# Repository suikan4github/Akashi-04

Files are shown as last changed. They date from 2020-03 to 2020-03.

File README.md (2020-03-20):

# Akashi-04
Audio board for Nucleo-G431RB

## Functionality
This board is designed to provide the audio functionality for the  STM32 series MCU. 
The connectors can be directly mounted on the Nucleo 64 series board and employs I2S interface of STM32 MCU.
This board supports following Nucleo :
- STM32F446RE
- STM32G431RB

The design can be retrieved from the [github](https://github.com/suikan4github/Akashi-04) repository.

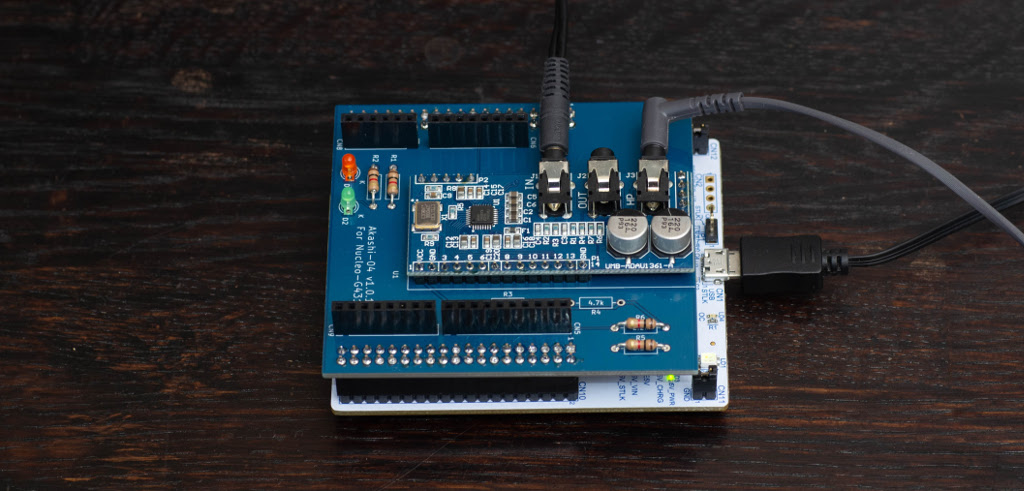
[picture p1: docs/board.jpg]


These functionalities are tested with following codec board as with I2C control line. 
- [UMB-ADAU1361A](http://dsps.shop-pro.jp/?pid=82798273)

## Development
- [KiCad 5.1](http://kicad-pcb.org/blog/2019/03/KiCad-5.1.0-Release/)
- [Nucleo G431RB](https://www.st.com/en/evaluation-tools/nucleo-g431rb.html)
- [Nucleo F446RE](https://www.st.com/en/evaluation-tools/nucleo-f446re.html)

The schematics [can be downloaded](docs/Akashi-04.pdf) as PDF format. 

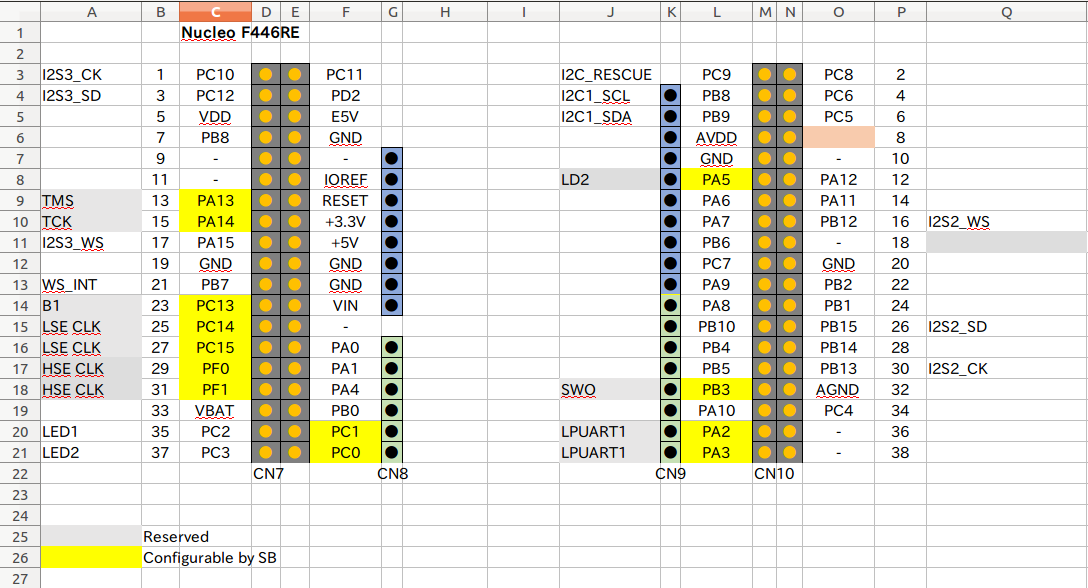
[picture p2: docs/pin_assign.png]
Pin Configurations


The configuration of special ports are :
- I2S2 : Slave TX
- I2S3 : Slave RX
- PB7 : EXTI to detect the I2S WS edge. 
- PC9 : Open Drain output. To save the struggled I2C device.

## I2C address
By default, the I2C device address are configured as ***0x38*** ( 7bit address ). 
If you want to change, you should modify the short bridge as following : 

| JP1    | JP2    | Address |
---------|--------|---------|
| Closed | Closed | 0x38    |
| Open   | Closed | 0x39    |
| Closed | Open   | 0x3A    |
| Open   | Open   | 0x3B    |

Note that R3 and R4 are needed if JP1 and JP2 are cut, respectively

## Usage
To clone this project, follow :
```
git clone repository-of-this-project
git submodule update
```

The sample programs are published as [murasaki_samples_audio](https://github.com/suikan4github/murasaki_samples_audio) repositories. 

 To use these repository, follow the sequence :
 1. Clone the murasaki_samples_audio repository
 1. Import to CubeIDE

Caution : Because of the height of the capacitor, the stacked Arduino board may contact to the capacitor. 

## License
This PCB design is released under the [Creative Commons Attribution 4.0 International license](https://creativecommons.org/licenses/by/4.0/). 
You are welcome to use this design for commercial purposes.

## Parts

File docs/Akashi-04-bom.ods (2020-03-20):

Reference | Quantity | Value | Footprint | Datasheet
CN5 | 1 | Conn_01x10 | Connector_PinHeader_2.54mm:PinHeader_1x10_P2.54mm_Vertical | Arduino Stackable
CN6 CN9 | 2 | Conn_01x08 | Connector_PinHeader_2.54mm:PinHeader_1x08_P2.54mm_Vertical | Arduino Stackable
CN8 | 1 | Conn_01x06 | Connector_PinHeader_2.54mm:PinHeader_1x06_P2.54mm_Vertical | Arduino Stackable
CN7 CN10 | 2 | Conn_02x19 | Connector_PinSocket_2.54mm:PinSocket_2x19_P2.54mm_Vertical | PPPC192LFBN-RC
D1 D2 | 2 | LED | LED_THT:LED_D3.0mm_Clear | ~
R1 R2 | 2 | 1k | Resistor_THT:R_Axial_DIN0207_L6.3mm_D2.5mm_P10.16mm_Horizontal | ~
R3 | 1 | 4.7k | Resistor_THT:R_Axial_DIN0207_L6.3mm_D2.5mm_P10.16mm_Horizontal | ~
R9 R5 | 2 | 2.2k | Resistor_THT:R_Axial_DIN0207_L6.3mm_D2.5mm_P10.16mm_Horizontal | ~
U1 | 1 | UMB-ADAU1361A | Codec_Modules:UMB-ADAU1361A | http://dsps.shop-pro.jp/?pid=82798273

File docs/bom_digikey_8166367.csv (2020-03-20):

メーカー品番 | 仕入先 | Digi-Key品番 | 客先参照品番（任意） | 参照名 | 梱包形態 | 部品状況 | 数量 | 単価 | 金額 | 在庫数量 | メーカー標準リードタイム | 商品概要 | RoHS ステータス | 鉛フリーステータス | REACHステータス
PPPC192LFBN-RC | Sullins Connector Solutions | S7122-ND |  | CN7,CN10 | トレイ | アクティブ | 2 | 265.00000 | ¥530 | 798 | 5 週間 | CONN HDR 38POS 0.1 GOLD PCB | ROHS3対応 | 鉛フリー | REACHの影響なし
85 | Adafruit Industries LLC | 1528-1074-ND |  | CN5,CN6,CN8,CN9 | バルク | アクティブ | 1 | 229.00000 | ¥229 | 3872 | 4 週間 | STACKING HEADER ARDUINO SHIELD | ROHS3対応 | 鉛フリー | Not Available

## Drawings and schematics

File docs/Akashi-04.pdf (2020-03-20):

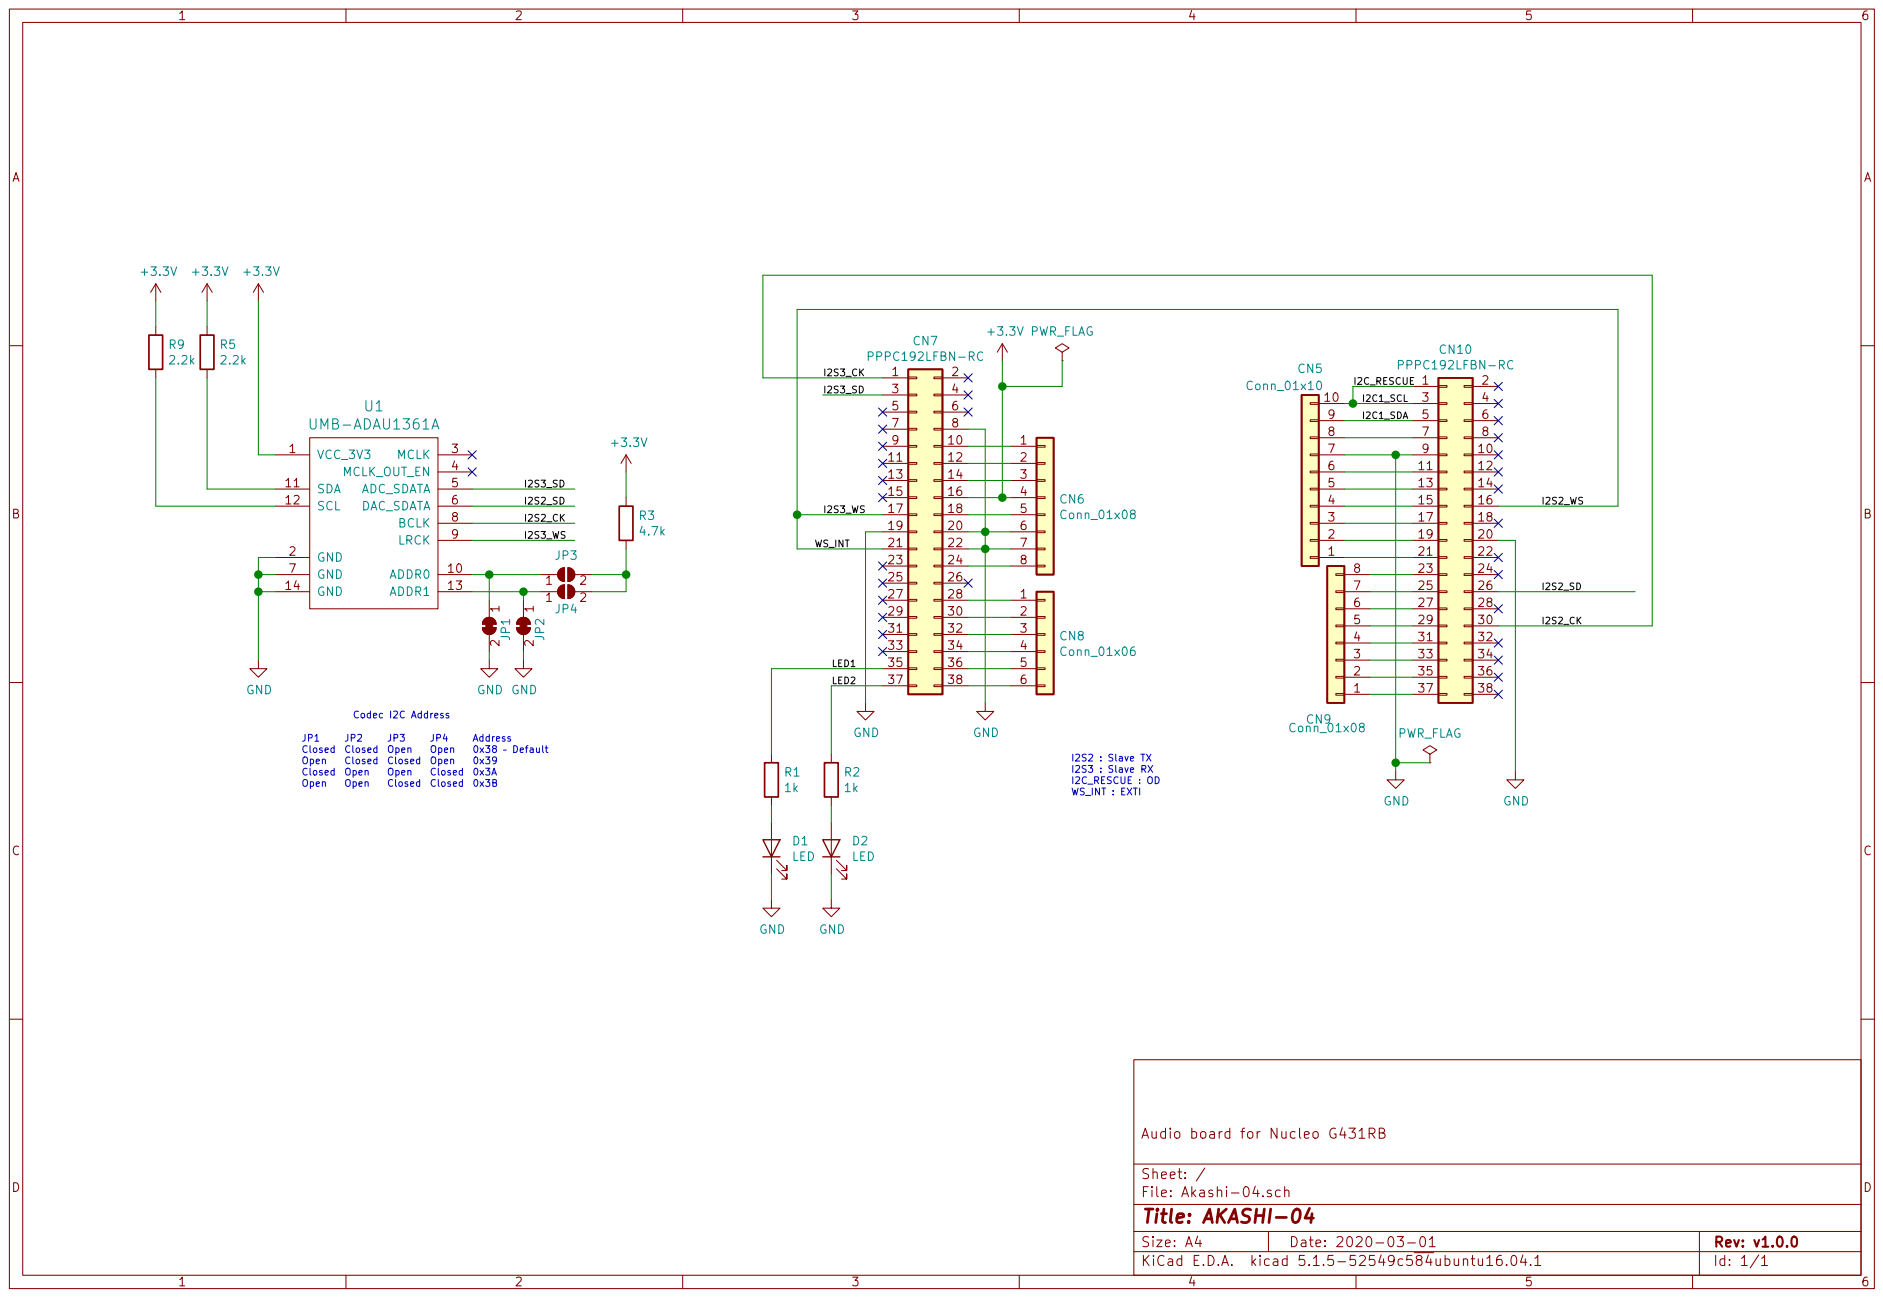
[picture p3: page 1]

19 | 20 | 6
21 | 22 | 7

8 CN9 Conn_01x08 5 | 29

LED2 | 37 | 38

JP1 Closed Open Closed Open

JP2 Closed Closed Open Open

JP3 Open Closed Open Closed

JP4 Open Open Closed Closed

File: Akashi-04.sch Sheet: / Audio board for Nucleo G431RB

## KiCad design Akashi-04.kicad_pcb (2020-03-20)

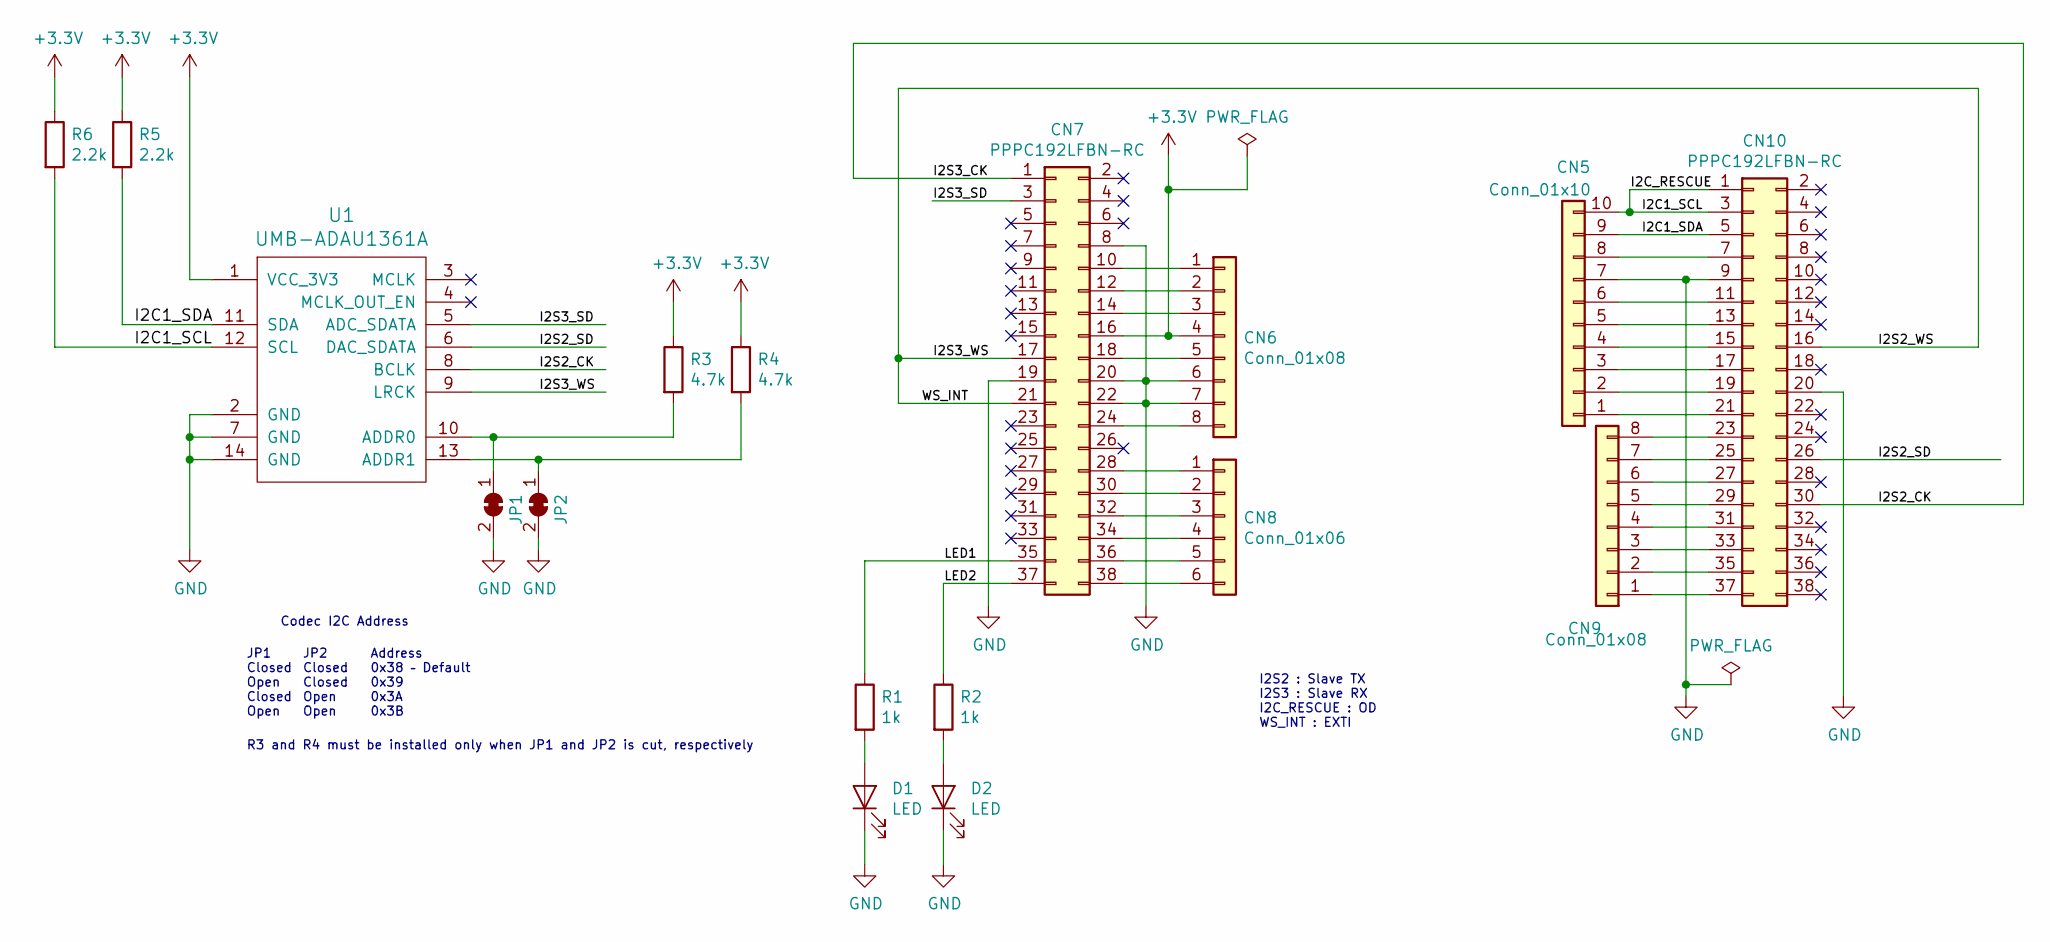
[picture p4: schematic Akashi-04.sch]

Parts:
CN5: Conn_01x10; PinHeader_1x10_P2.54mm_Vertical
CN6, CN9: Conn_01x08; PinHeader_1x08_P2.54mm_Vertical
CN7, CN10: PPPC192LFBN-RC; PinSocket_2x19_P2.54mm_Vertical
CN8: Conn_01x06; PinHeader_1x06_P2.54mm_Vertical
D1, D2: LED; LED_D3.0mm_Clear
JP1, JP2: SolderJumper_2_Bridged; SolderJumper-2_P1.3mm_Bridged_RoundedPad1.0x1.5mm
R1, R2: 1k; R_Axial_DIN0207_L6.3mm_D2.5mm_P10.16mm_Horizontal
R3, R4: 4.7k; R_Axial_DIN0207_L6.3mm_D2.5mm_P10.16mm_Horizontal
R5, R6: 2.2k; R_Axial_DIN0207_L6.3mm_D2.5mm_P10.16mm_Horizontal
U1: UMB-ADAU1361A

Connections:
+3V3: CN6.4, CN7.16, R3.1, R4.1, R5.1, R6.1, U1.1 (VCC_3V3)
/I2C1_SCL: CN5.10, CN10.1, CN10.3, R6.2, U1.12 (SCL)
/I2C1_SDA: CN5.9, CN10.5, R5.2, U1.11 (SDA)
/I2S2_CK: CN7.1, CN10.30, U1.8 (BCLK)
/I2S2_SD: CN10.26, U1.6 (DAC_SDATA)
/I2S2_WS: CN7.17, CN7.21, CN10.16, U1.9 (LRCK)
/I2S3_SD: CN7.3, U1.5 (ADC_SDATA)
/LED1: CN7.35, R1.1
/LED2: CN7.37, R2.1
GND: CN5.7, CN6.6, CN6.7, CN7.8, CN7.19, CN7.20, CN7.22, CN10.9, CN10.20, D1.1 (K), D2.1 (K), JP1.2 (B), JP2.2 (B), U1.2 (GND), U1.7 (GND), U1.14 (GND)
unnamed: CN6.1, CN7.10
unnamed: CN6.2, CN7.12
unnamed: CN6.3, CN7.14
unnamed: CN6.5, CN7.18
unnamed: CN6.8, CN7.24
unnamed: CN7.28, CN8.1
unnamed: CN7.30, CN8.2
unnamed: CN7.32, CN8.3
unnamed: CN7.34, CN8.4
unnamed: CN7.36, CN8.5
unnamed: CN7.38, CN8.6
unnamed: CN5.8, CN10.7
unnamed: CN5.6, CN10.11
unnamed: CN5.5, CN10.13
unnamed: CN5.4, CN10.15
unnamed: CN5.3, CN10.17
unnamed: CN5.2, CN10.19
unnamed: CN5.1, CN10.21
unnamed: CN9.8, CN10.23
unnamed: CN9.7, CN10.25
unnamed: CN9.6, CN10.27
unnamed: CN9.5, CN10.29
unnamed: CN9.4, CN10.31
unnamed: CN9.3, CN10.33
unnamed: CN9.2, CN10.35
unnamed: CN9.1, CN10.37
unnamed: D1.2 (A), R1.2
unnamed: D2.2 (A), R2.2
unnamed: JP1.1 (A), R3.2, U1.10 (ADDR0)
unnamed: JP2.1 (A), R4.2, U1.13 (ADDR1)

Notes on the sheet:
JP1 Closed Open Closed Open
JP2 Closed Closed Open Open
Address 0x38 – Default 0x39 0x3A 0x3B
Codec I2C Address
I2S2 : Slave TX I2S3 : Slave RX I2C_RESCUE : OD WS_INT : EXTI
R3 and R4 must be installed only when JP1 and JP2 is cut, respectively

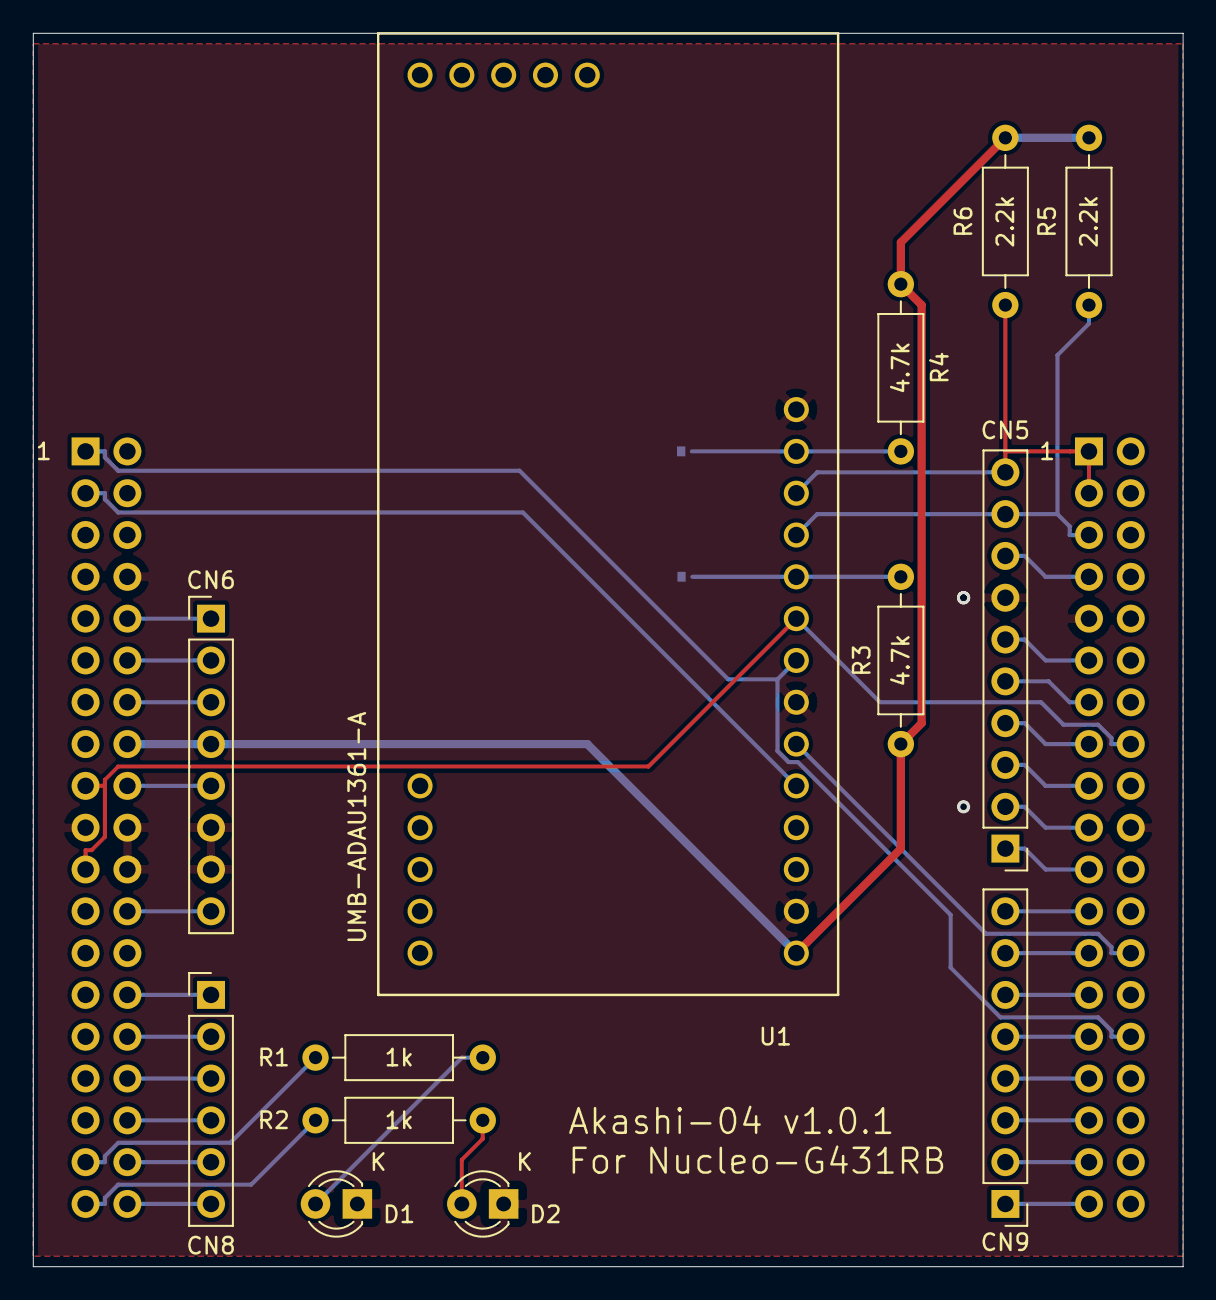
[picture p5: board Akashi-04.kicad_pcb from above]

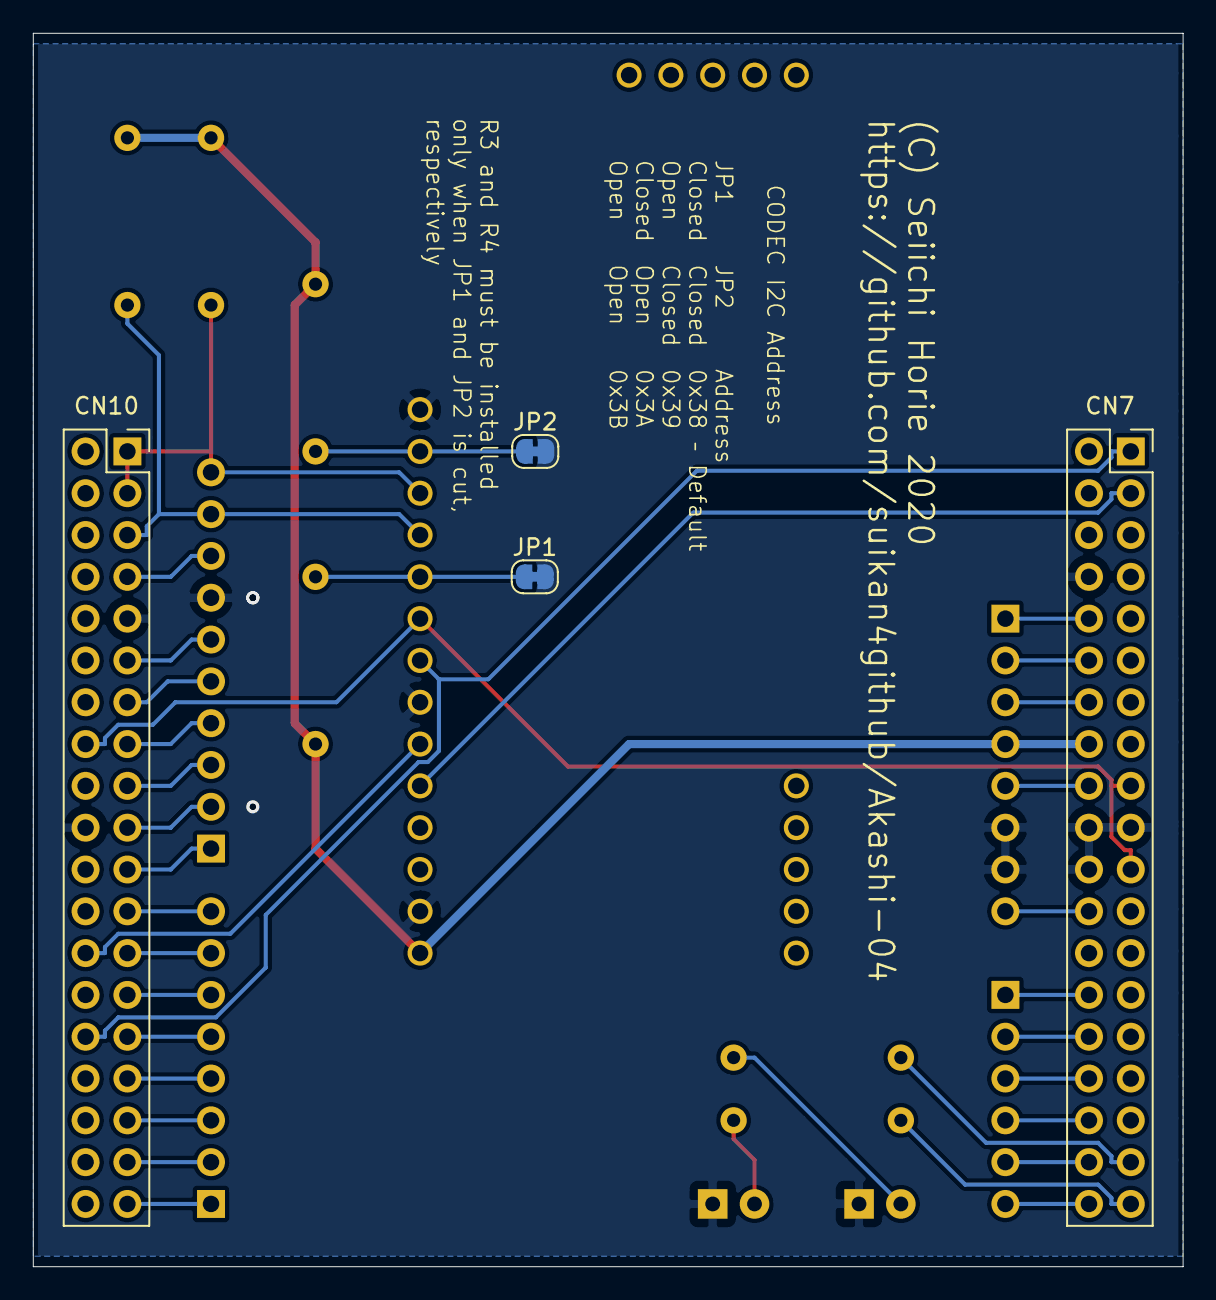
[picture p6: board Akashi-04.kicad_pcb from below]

Board: 2 copper layers, 69.9 x 74.9 mm, 17 parts (4 on the bottom side), 40 nets.

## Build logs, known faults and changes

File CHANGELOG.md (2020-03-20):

# Change log
Record of the modification in project development.
## [Unreleased]

### Added
### Changed
### Deprecated
### Removed
### Fixed
### Security
### Known Issue

## [1.0.1] - 2020-03-21

### Added
### Changed
### Deprecated
### Removed
### Fixed
- [Issue 1 : CODEC I2C is not connected.  ](https://github.com/suikan4github/Akashi-04/issues/1)

### Security
### Known Issue

## [1.0.0] - 2020-03-03
Initial release. 

### Added
### Changed
### Deprecated
### Removed
### Fixed
### Security

[Unreleased]: https://github.com/suikan4github/Akashi-04/compare/v1.0.1...develop
[1.0.1]: https://github.com/suikan4github/Akashi-04/compare/v1.0.0...v1.0.1
[1.0.0]: https://github.com/suikan4github/Akashi-04/compare/v0.0.0...v1.0.0

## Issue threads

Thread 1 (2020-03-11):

CODEC I2C is not connected.

suikan4github, 2020-03-11:
There is no connection between CODEC and I2C connector of the pin header.

suikan4github, 2020-03-20:
Fixed by v1.0.1

Closed 2020-03-20.

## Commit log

2020-02-16 Revert "Initial commit"
    This reverts commit f868d28a5865c707f290b649e922866782d35e7e.
    [Akashi-04.kicad_pcb, Akashi-04.sch]
2020-02-16 Rough design
    [Akashi-04.kicad_pcb, Akashi-04.sch]
2020-02-16 Designe done
    [Akashi-04.kicad_pcb, Akashi-04.sch]
2020-02-23 Added I2C clock rescue
    [Akashi-04-pin-config.ods, Akashi-04.kicad_pcb, Akashi-04.sch]
2020-03-01 Added rescue line of I2C and I2S WS int
    I2C rescue is needed to toggle the I2C SCL inc case of
    the device is stretching signal by fault.
    I2S WS int is needed to start the audio in the correct timing.
    [Akashi-04.kicad_pcb, Akashi-04.sch]
2020-03-01 Generated v1.0.0 gerber
    [Akashi-04-bom.ods, Akashi-04-pin-assign.ods, Akashi-04-pin-config.ods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]
2020-03-12 Moved resister
    [Akashi-04.kicad_pcb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]
2020-03-12 Moved label
    [Akashi-04.kicad_pcb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]
2020-03-20 Added board photo.
